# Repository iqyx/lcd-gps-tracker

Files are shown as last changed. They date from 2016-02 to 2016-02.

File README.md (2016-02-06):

GPS tracker with a simple LCD interface
==================================================

After much negative experience with Android GPS tracking (battery usage, bad
reception) I decided to build my own dedicated GPS tracker despite the fact that
multiple similar devices are readily available on the market.

Selected components
----------------------

  * Quectel L70B GPS receiver module with low power tracking function. They claim
    1.4mA tracking current draw under static conditions. We will see.
  * STM32F401 microcontroller in a QFN48 package, low power run mode
  * EA DOGS 102x64px graphic LCD module with low power consumption (0.25mA)
  * USB connections for charging and downloading data
  * SPI serial flash for data storage (8Mbit/16Mbt)
  * 600mAh 3.7V LiPo cell

Battery and memory size
----------------------------

The goal is 5mA current draw which should be enough to provide nearly 4 days of
continuous logging using the mentioned 600mAh LiPo cell. Such cells are
available in local stores or on eBay.

The following items will be saved:

  * 32 bits for the actual time
  * 32 bits for latitude
  * 32 bits for longitude
  * 16 bits for height
  * 16 bits reserved for header and other data

Which gives 16 bytes for a single point or 65536 points in a 1MB flash memory.
Considering 5 second logging interval (should be enough fir hiking), the flash
memory should suffice for 91 hours of logging, which is nearly 4 days.

Project status
------------------

As of 2016-02-06, basic requirements are determined and the schematic is ready.
Board layout is WIP.

Bill of materials
----------------------

TODO

Schematic and layout pictures
----------------------------------

[schematic](doc/schematic.png)

Prototype photos
-------------------

TODO

Resources
--------------

You can access the schematic/layout files and firmware at
[https://github.com/iqyx/lcd-gps-tracker](https://github.com/iqyx/lcd-gps-tracker)

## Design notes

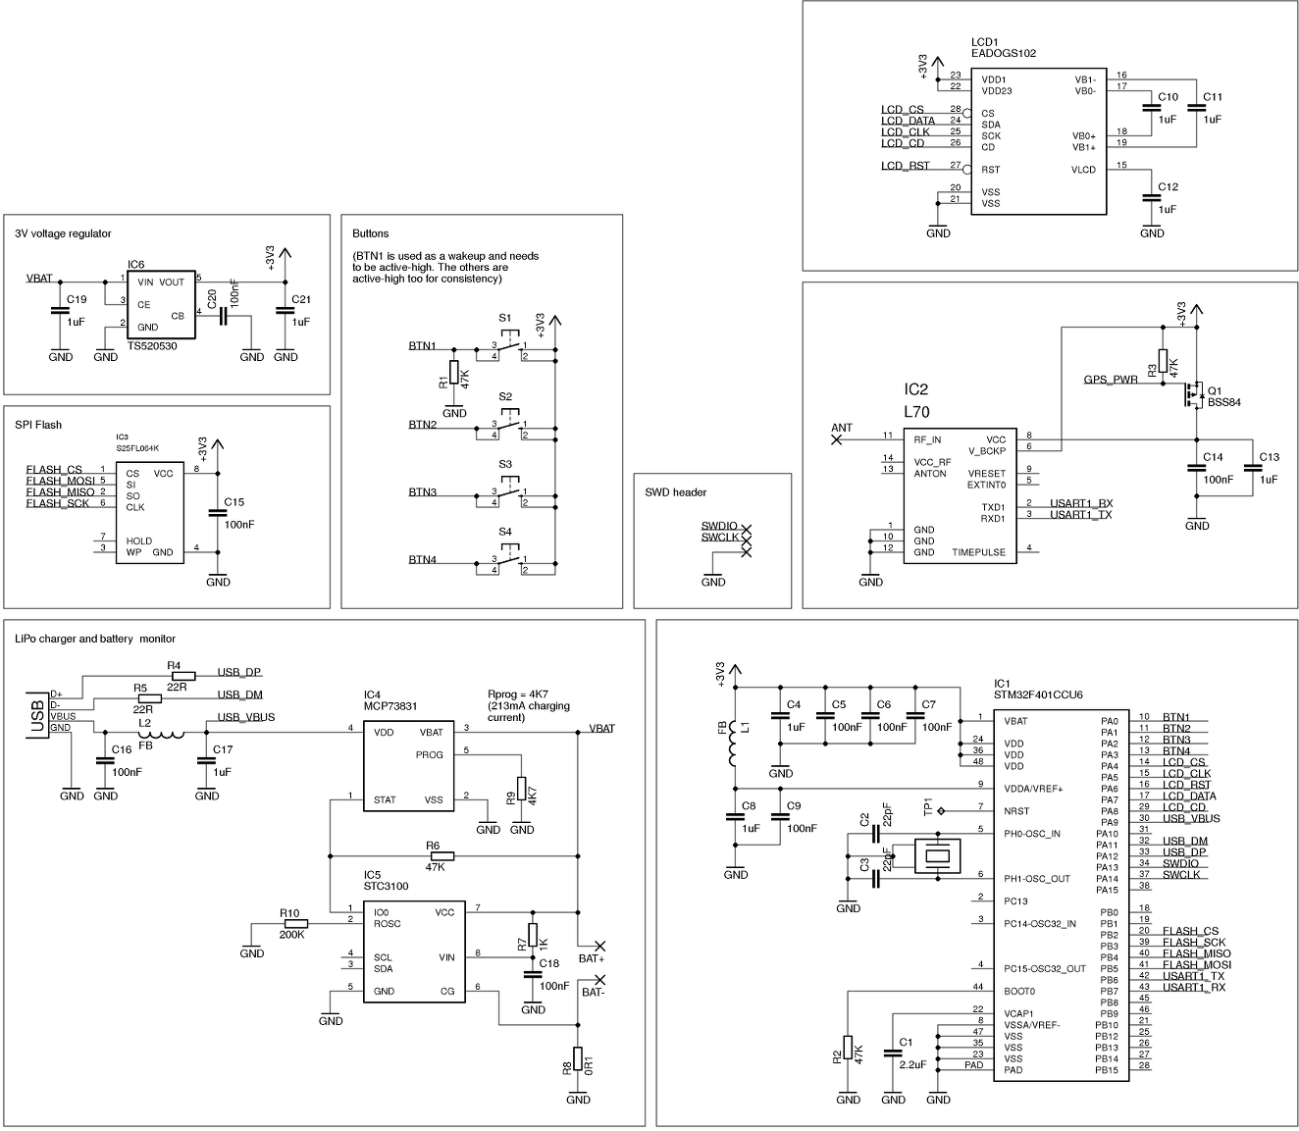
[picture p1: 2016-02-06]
doc/schematic.png

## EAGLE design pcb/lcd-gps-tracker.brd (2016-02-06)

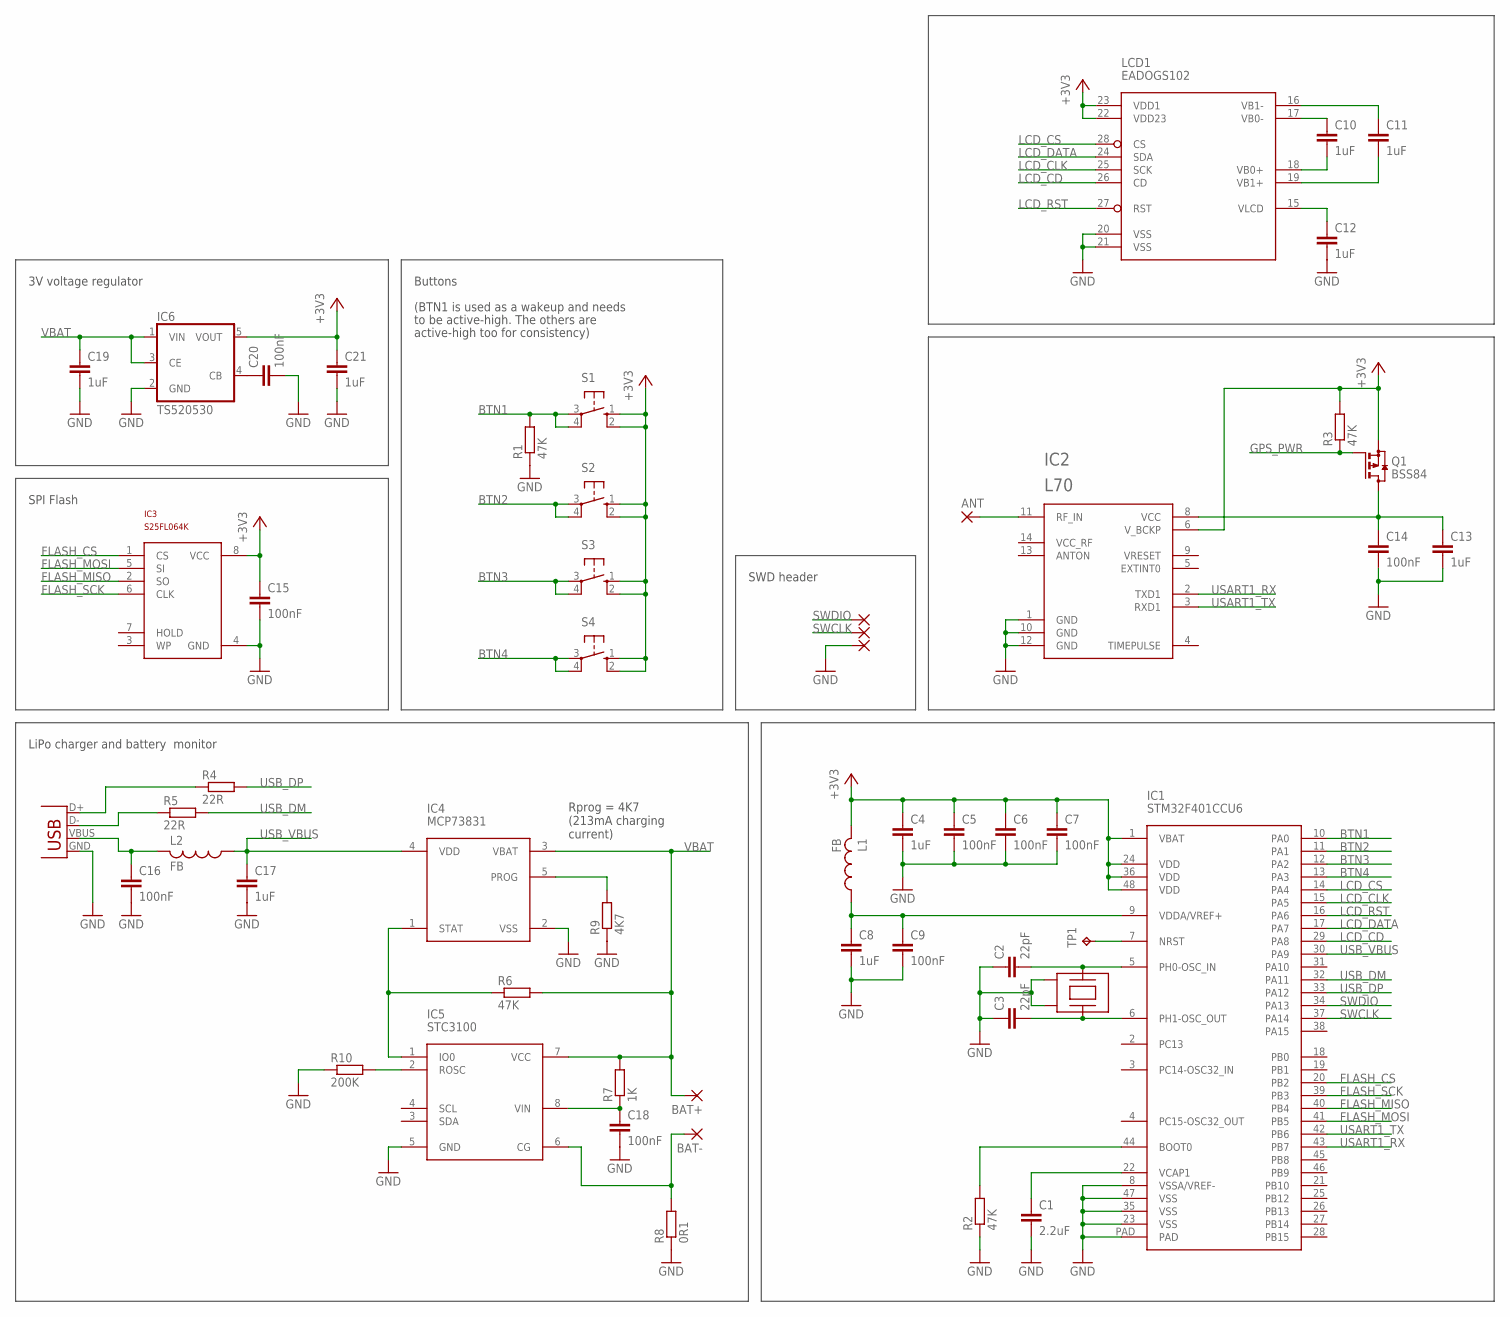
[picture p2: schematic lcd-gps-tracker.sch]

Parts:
ANT: 2,54/1,0
BAT+: SMD2; SMD1,27-2,54
BAT-: SMD2; SMD1,27-2,54
C1: 2.2uF; C0805
C2, C3: 22pF; C0603
C4, C8, C10, C11, C12, C13, C19, C21: 1uF; C0603
C5, C6, C7, C9, C14, C15, C16, C18, C20: 100nF; C0603
C17: 1uF; C0805
IC1: STM32F401CCU6; UFQFPN48
IC2: L70
IC3: S25FL064K; SO-08M
IC4: MCP73831; SOT23-5
IC5: STC3100; MSOP8
IC6: TS520530; SOT25
L1, L2: FB; L2012C
LCD1: EADOGS102; EADOGS
Q1: BSS84; SOT23
R1, R2, R3, R6: 47K; R0603
R4, R5: 22R; R0603
R7: 1K; R0603
R8: 0R1; R0805
R9: 4K7; R0603
R10: 200K; R0603
S1, S2, S3, S4: 10-XX; B3F-10XX
SWCLK: SMD2; SMD1,27-2,54
SWDIO: SMD2; SMD1,27-2,54
SWGND: SMD2; SMD1,27-2,54
TP1: TPB1,27; B1,27
U$1: XTAL-7M; XTAL_7M
X1: USB-MICROB

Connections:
+3V3: C4.1, C5.1, C6.1, C7.1, C15.1, C21.1, IC1.1 (VBAT), IC1.24 (VDD), IC1.36 (VDD), IC1.48 (VDD), IC2.6 (V_BCKP), IC3.8 (VCC), IC6.5 (VOUT), L1.2, LCD1.22 (VDD23), LCD1.23 (VDD1), Q1.2 (S), R3.2, S1.1 (S), S1.2 (S1), S2.1 (S), S2.2 (S1), S3.1 (S), S3.2 (S1), S4.1 (S), S4.2 (S1)
BTN1: IC1.10 (PA0), R1.2, S1.3, S1.4 (P1)
BTN2: IC1.11 (PA1), S2.3, S2.4 (P1)
BTN3: IC1.12 (PA2), S3.3, S3.4 (P1)
BTN4: IC1.13 (PA3), S4.3, S4.4 (P1)
FLASH_CS: IC1.20 (PB2), IC3.1 (CS)
FLASH_MISO: IC1.40 (PB4), IC3.2 (SO)
FLASH_MOSI: IC1.41 (PB5), IC3.5 (SI)
FLASH_SCK: IC1.39 (PB3), IC3.6 (CLK)
GND: C1.2, C2.1, C3.1, C4.2, C5.2, C6.2, C7.2, C8.2, C9.2, C12.2, C13.2, C14.2, C15.2, C16.2, C17.2, C18.2, C19.2, C20.2, C21.2, IC1.8 (VSSA/VREF-), IC1.23 (VSS), IC1.35 (VSS), IC1.47 (VSS), IC1.PAD, IC2.1 (GND), IC2.10 (GND), IC2.12 (GND), IC3.4 (GND), IC4.2 (VSS), IC5.5 (GND), IC6.2 (GND), LCD1.20 (VSS), LCD1.21 (VSS), R1.1, R2.1, R8.1, R9.1, R10.1, SWGND.1, U$1.2 (G1), U$1.4 (G2), X1.GND
GPS_PWR: Q1.1 (G), R3.1
LCD_CD: IC1.29 (PA8), LCD1.26 (CD)
LCD_CLK: IC1.15 (PA5), LCD1.25 (SCK)
LCD_CS: IC1.14 (PA4), LCD1.28 (CS)
LCD_DATA: IC1.17 (PA7), LCD1.24 (SDA)
LCD_RST: IC1.16 (PA6), LCD1.27 (RST)
unnamed: C16.1, L2.2, X1.VBUS
unnamed: R5.1, X1.D-
unnamed: C1.1, IC1.22 (VCAP1)
unnamed: IC1.44 (BOOT0), R2.2
unnamed: C2.2, IC1.5 (PH0-OSC_IN), U$1.1
unnamed: C3.2, IC1.6 (PH1-OSC_OUT), U$1.3 (2)
unnamed: IC1.7 (NRST), TP1.TP
unnamed: C12.1, LCD1.15 (VLCD)
unnamed: C10.2, LCD1.18 (VB0+)
unnamed: C8.1, C9.1, IC1.9 (VDDA/VREF+), L1.1
unnamed: C10.1, LCD1.17 (VB0-)
unnamed: C11.1, LCD1.16 (VB1-)
unnamed: C11.2, LCD1.19 (VB1+)
unnamed: C13.1, C14.1, IC2.8 (VCC), Q1.3 (D)
unnamed: ANT.1, IC2.11 (RF_IN)
unnamed: R4.1, X1.D+
unnamed: IC4.1 (STAT), IC5.1 (IO0), R6.1
unnamed: IC4.5 (PROG), R9.2
unnamed: C18.1, IC5.8 (VIN), R7.1
unnamed: BAT-.1, IC5.6 (CG), R8.2
unnamed: IC5.2 (ROSC), R10.2
unnamed: C20.1, IC6.4 (CB)
SWCLK: IC1.37 (PA14), SWCLK.1
SWDIO: IC1.34 (PA13), SWDIO.1
USART1_RX: IC1.43 (PB7), IC2.2 (TXD1)
USART1_TX: IC1.42 (PB6), IC2.3 (RXD1)
USB_DM: IC1.32 (PA11), R5.2
USB_DP: IC1.33 (PA12), R4.2
USB_VBUS: C17.1, IC1.30 (PA9), IC4.4 (VDD), L2.1
VBAT: BAT+.1, C19.1, IC4.3 (VBAT), IC5.7 (VCC), IC6.1 (VIN), IC6.3 (CE), R6.2, R7.2

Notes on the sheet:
SWD header
Buttons
(BTN1 is used as a wakeup and needs
to be active-high. The others are
active-high too for consistency)
3V voltage regulator
SPI Flash
Rprog = 4K7 (213mA charging current)
LiPo charger and battery monitor

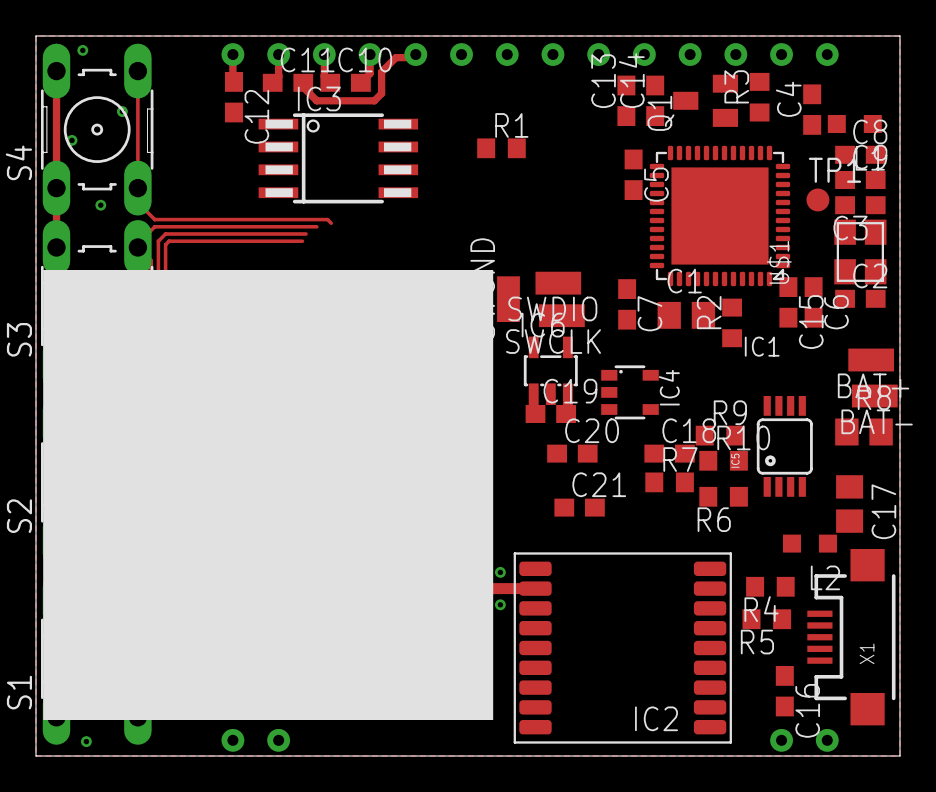
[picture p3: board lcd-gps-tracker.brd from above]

Board: 2 copper layers, 48.0 x 40.0 mm, 54 parts (1 on the bottom side), 46 nets.

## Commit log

2016-02-06 Add schematic and layout files (first revision)
    [lcd-gps-tracker.brd, lcd-gps-tracker.sch]
2016-02-06 Add project status and schematic picture to README.md

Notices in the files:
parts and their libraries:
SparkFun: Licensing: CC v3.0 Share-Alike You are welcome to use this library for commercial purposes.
